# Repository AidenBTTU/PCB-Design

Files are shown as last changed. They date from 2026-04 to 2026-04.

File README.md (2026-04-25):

This repository holds the Custom PCB Design I have done during my degree so far. This includes a step counting device with I2C and USB communication, an external crystal oscillator, and a power system with battery charging capabilities aswell as a seperate PCB for driving motors.

# Step Count PCB V2



# Motor Driver PCB



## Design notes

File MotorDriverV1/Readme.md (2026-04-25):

The motor driver pcb designed in this folder was designed to operate with 6V TT Motors from a Raspberry Pi Pico. A signal voltage taken off a shunt resistor is amplified on board to be sent to a seperate overcurrent detection board. The PCB is designed to be operated with 2-4 TT motors controlled in pairs. Connectors are designed with the Raspberry Pi Pico in mind. Current through motors is not designed to handle more than 2A collectively. LFWD & LREV, RFWD & RREV are exclusive pairs and should not be held high at the same time or else through-current is likely. Pull up resistors allow the board to be operated from a digital voltage supply, but signal pins have only been tested at 3.3V. Mosfets used are the readily available IRLZ44N and IRF4905. The resistor used should be 500mohm or greater if using long or thin cables, capable of handling at least 1W.

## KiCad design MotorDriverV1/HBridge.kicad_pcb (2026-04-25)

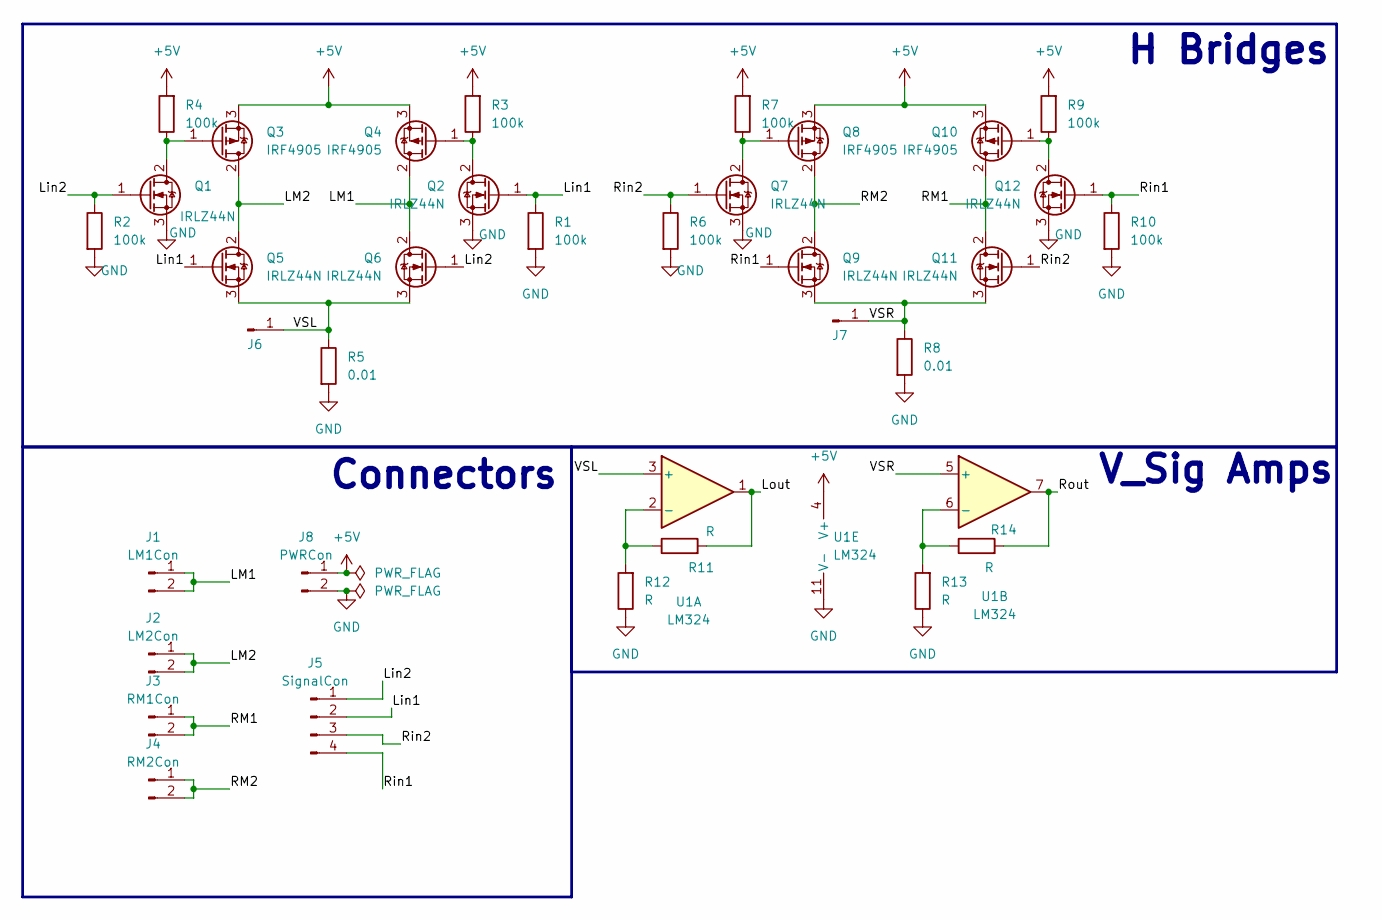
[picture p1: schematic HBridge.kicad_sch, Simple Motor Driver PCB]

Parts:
J1: LM1Con; PinHeader_1x02_P2.54mm_Vertical
J2: LM2Con; PinHeader_1x02_P2.54mm_Vertical
J3: RM1Con; PinHeader_1x02_P2.54mm_Vertical
J4: RM2Con; PinHeader_1x02_P2.54mm_Vertical
J5: SignalCon; PinHeader_1x04_P2.54mm_Vertical
J6, J7: Conn_01x01_Pin; PinHeader_1x01_P2.54mm_Vertical
J8: PWRCon; PinHeader_1x02_P2.54mm_Vertical
Q1, Q2, Q5, Q6, Q7, Q9, Q11, Q12: IRLZ44N; TO-220-3_Vertical
Q3, Q4, Q8, Q10: IRF4905; TO-220-3_Vertical
R1, R2, R3, R4, R6, R7, R9, R10: 100k; R_Axial_DIN0207_L6.3mm_D2.5mm_P7.62mm_Horizontal
R5, R8: 0.01; R_Axial_DIN0414_L11.9mm_D4.5mm_P15.24mm_Horizontal
R11, R12, R13, R14: R; R_Axial_DIN0207_L6.3mm_D2.5mm_P7.62mm_Horizontal
U1: LM324; DIP-14_W7.62mm_Socket

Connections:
+5V: J8.1, Q3.3 (S), Q4.3 (S), Q8.3 (S), Q10.3 (S), R3.2, R4.2, R7.2, R9.2, U1.4 (V+)
/LM1: J1.1, J1.2, Q4.2 (D), Q6.2 (D)
/LM2: J2.1, J2.2, Q3.2 (D), Q5.2 (D)
/Lin1: J5.2, Q2.1 (G), Q5.1 (G), R1.1
/Lin2: J5.1, Q1.1 (G), Q6.1 (G), R2.1
/Lout: R11.2, U1.1
/RM1: J3.1, J3.2, Q10.2 (D), Q11.2 (D)
/RM2: J4.1, J4.2, Q8.2 (D), Q9.2 (D)
/Rin1: J5.4, Q9.1 (G), Q12.1 (G), R10.1
/Rin2: J5.3, Q7.1 (G), Q11.1 (G), R6.1
/Rout: R14.2, U1.7
/VSL: J6.1, Q5.3 (S), Q6.3 (S), R5.1, U1.3 (+)
/VSR: J7.1, Q9.3 (S), Q11.3 (S), R8.1, U1.5 (+)
GND: J8.2, Q1.3 (S), Q2.3 (S), Q7.3 (S), Q12.3 (S), R1.2, R2.2, R5.2, R6.2, R8.2, R10.2, R12.1, R13.1, U1.11 (V-)
unnamed: Q1.2 (D), Q3.1 (G), R4.1
unnamed: Q2.2 (D), Q4.1 (G), R3.1
unnamed: Q7.2 (D), Q8.1 (G), R7.1
unnamed: Q10.1 (G), Q12.2 (D), R9.1
unnamed: R11.1, R12.2, U1.2 (-)
unnamed: R13.2, R14.1, U1.6 (-)

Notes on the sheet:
Connectors
V_Sig Amps
H Bridges

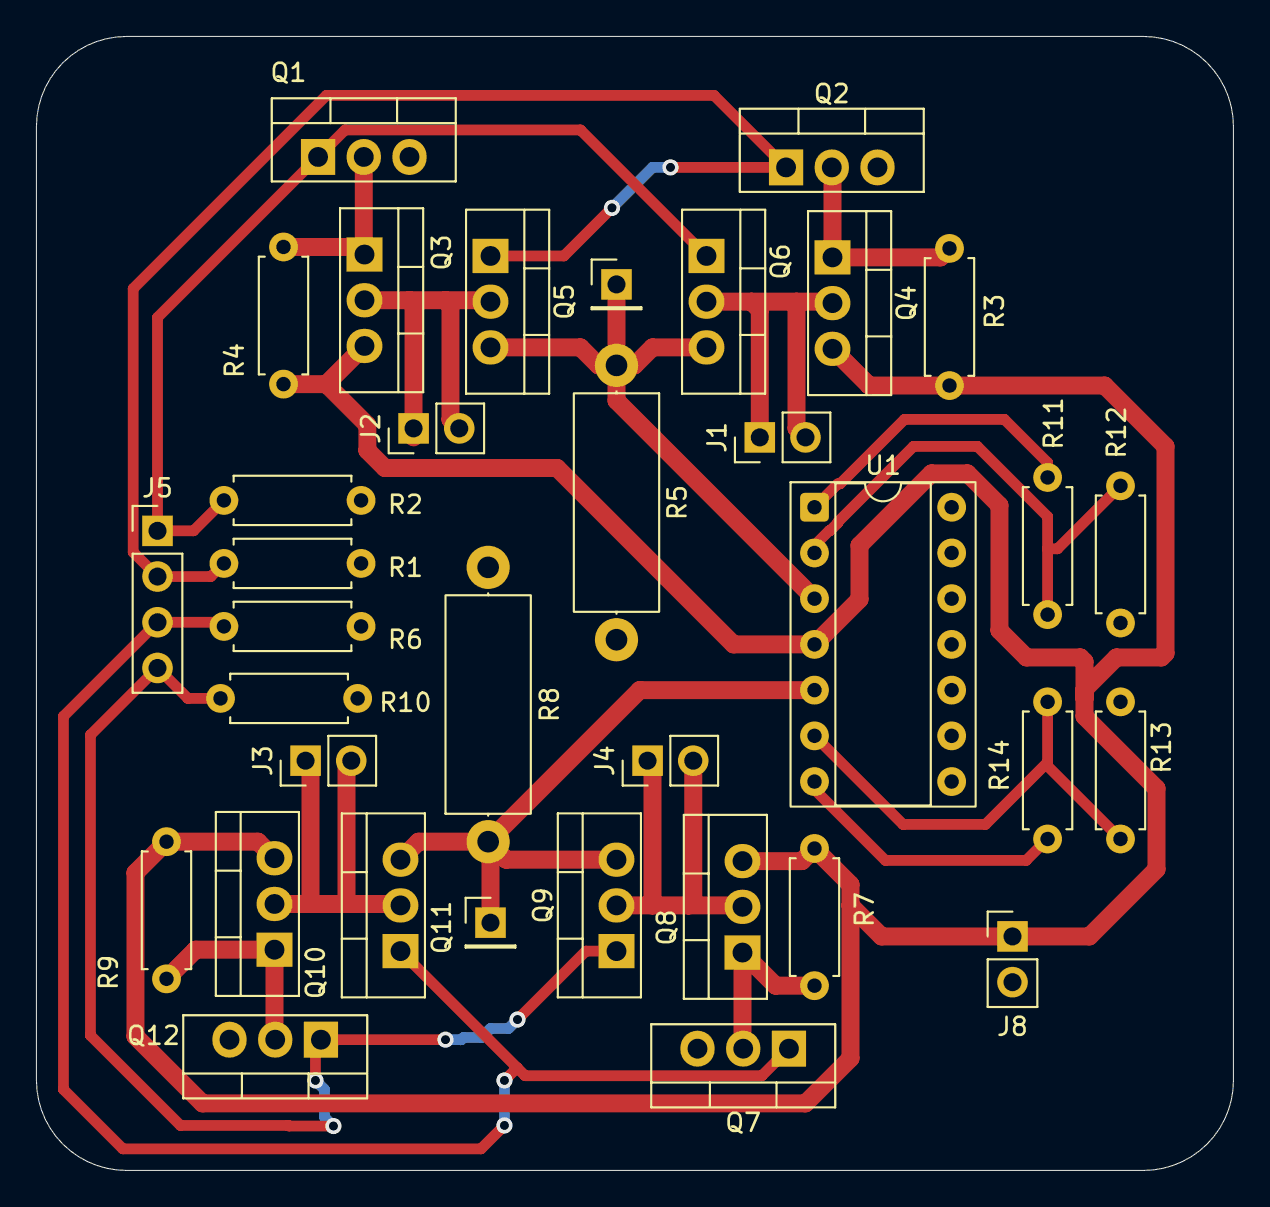
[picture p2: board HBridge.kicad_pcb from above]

Board: 2 copper layers, 66.5 x 63.0 mm, 35 parts (0 on the bottom side), 20 nets.

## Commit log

2026-04-25 Create Motor Driver
2026-04-25 Add image to Motor Driver documentation
2026-04-25 Revise README with project details and images
    Updated project description and added images for Step Count PCB V2 and Motor Driver PCB.
2026-04-25 Add README for MotorDriverV1 PCB details
2026-04-25 Update Readme with motor current and component info
    Added details about current handling and component specifications.
2026-04-25 PCB and schematic files
2026-04-25 Replace autosave PCB file with final version
    [HBridge.kicad_pcb]
2026-04-25 Update HBridge schematic file
    [HBridge.kicad_sch]
2026-04-25 Revise resistor requirements in Readme.md
